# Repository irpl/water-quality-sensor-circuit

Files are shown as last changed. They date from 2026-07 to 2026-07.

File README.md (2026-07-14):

# Water Quality Sensor Interface Board — Circuit

Design files for a board that reads a water quality sensor and uploads its readings over the cellular network. Designed in **Eagle 7.6**, laid out April 2018.

The sensor speaks **RS-232**, which a microcontroller cannot read directly. An **Arduino Nano** sits behind a **MAX233** transceiver that converts the sensor's incoming RS-232 signals down to TTL serial the Nano can read. The Nano then pushes the data to a remote server over cellular using a **SIM800** module with an ordinary SIM and data plan.

It is essentially a protocol-and-transport bridge: a legacy serial instrument on one end, a cellular uplink on the other, and level translation in between.

**Server:** [watermon](https://github.com/irpl/watermon) — the listener this board uploads to.

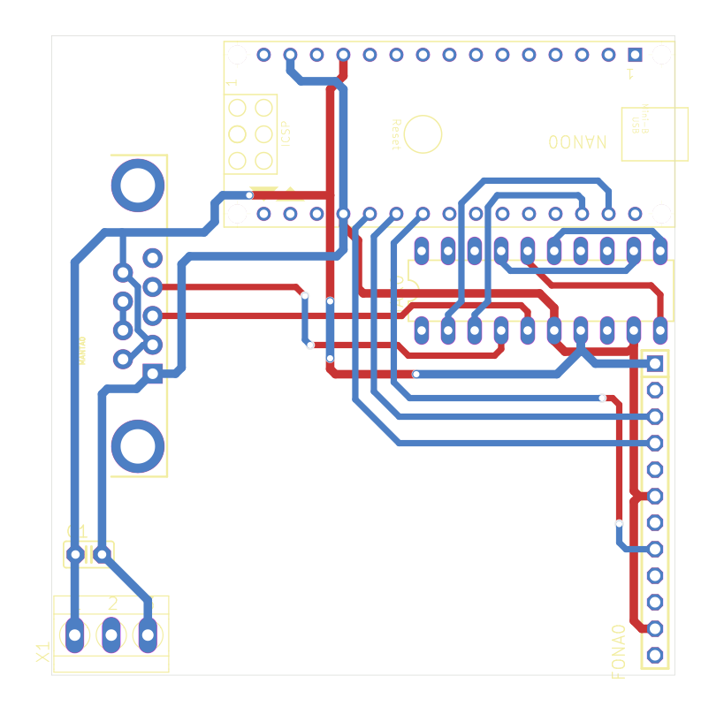
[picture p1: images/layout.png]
Copper layout


*Two-layer copper layout — red is the top layer, blue the bottom.*

## Design files

[`eagle/`](eagle/) contains the Eagle schematic (`.sch`) and board (`.brd`).

## Design notes

- **MAX233** rather than the more common MAX232: it integrates the charge-pump capacitors, so the level shifter needs no external capacitors — fewer parts to place, fewer things to fail in the field.
- **DB9 connector** on the board edge, so the sensor plugs straight in with a standard serial cable.
- Footprints for the **Arduino Nano** and the Adafruit **SIM800** cellular module, plus a 2×3 ICSP header.
- Screw terminal for field power.

The Eagle files carry no component values (only the terminal block is valued), so no BOM can be generated from them directly.

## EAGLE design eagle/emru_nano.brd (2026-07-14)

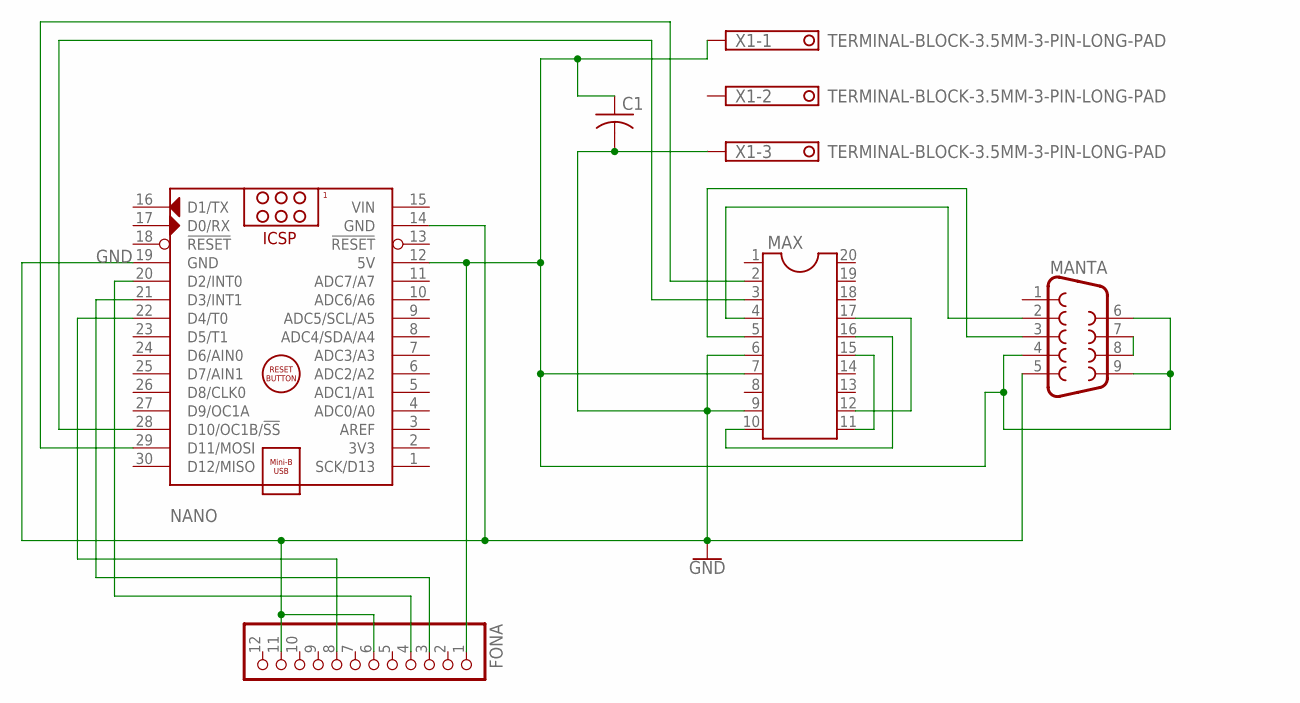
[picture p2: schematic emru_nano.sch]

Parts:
C1: C-US025-025X050; C025-025X050
FONA: PINHD-1X12; 1X12
MANTA: DB9MALE; DB9_MALE
MAX: DIL20
NANO: ARDUINO_NANO
X1: TERMINAL-BLOCK-3.5MM-3-PIN-LONG-PAD; TERMINAL-BLOCK-3-PIN-3.5MM-LONG-PAD

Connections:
GND: C1.2, FONA.6, FONA.11, MANTA.5, MAX.6, MAX.9, NANO.14 (GND), NANO.19 (GND), X1.3
unnamed: MANTA.7, MANTA.8
unnamed: FONA.4, NANO.20 (D2/INT0)
unnamed: C1.1, FONA.1, MANTA.4, MANTA.6, MANTA.9, MAX.7, NANO.12 (5V), X1.1
unnamed: MAX.10, MAX.16
unnamed: MAX.11, MAX.15
unnamed: MAX.12, MAX.17
unnamed: MANTA.2, MAX.4
unnamed: MANTA.3, MAX.5
unnamed: MAX.2, NANO.29 (D11/MOSI)
unnamed: MAX.3, NANO.28 (D10/OC1B/!SS)
unnamed: FONA.3, NANO.21 (D3/INT1)
unnamed: FONA.8, NANO.22 (D4/T0)
VIN: NANO.15 (VIN)

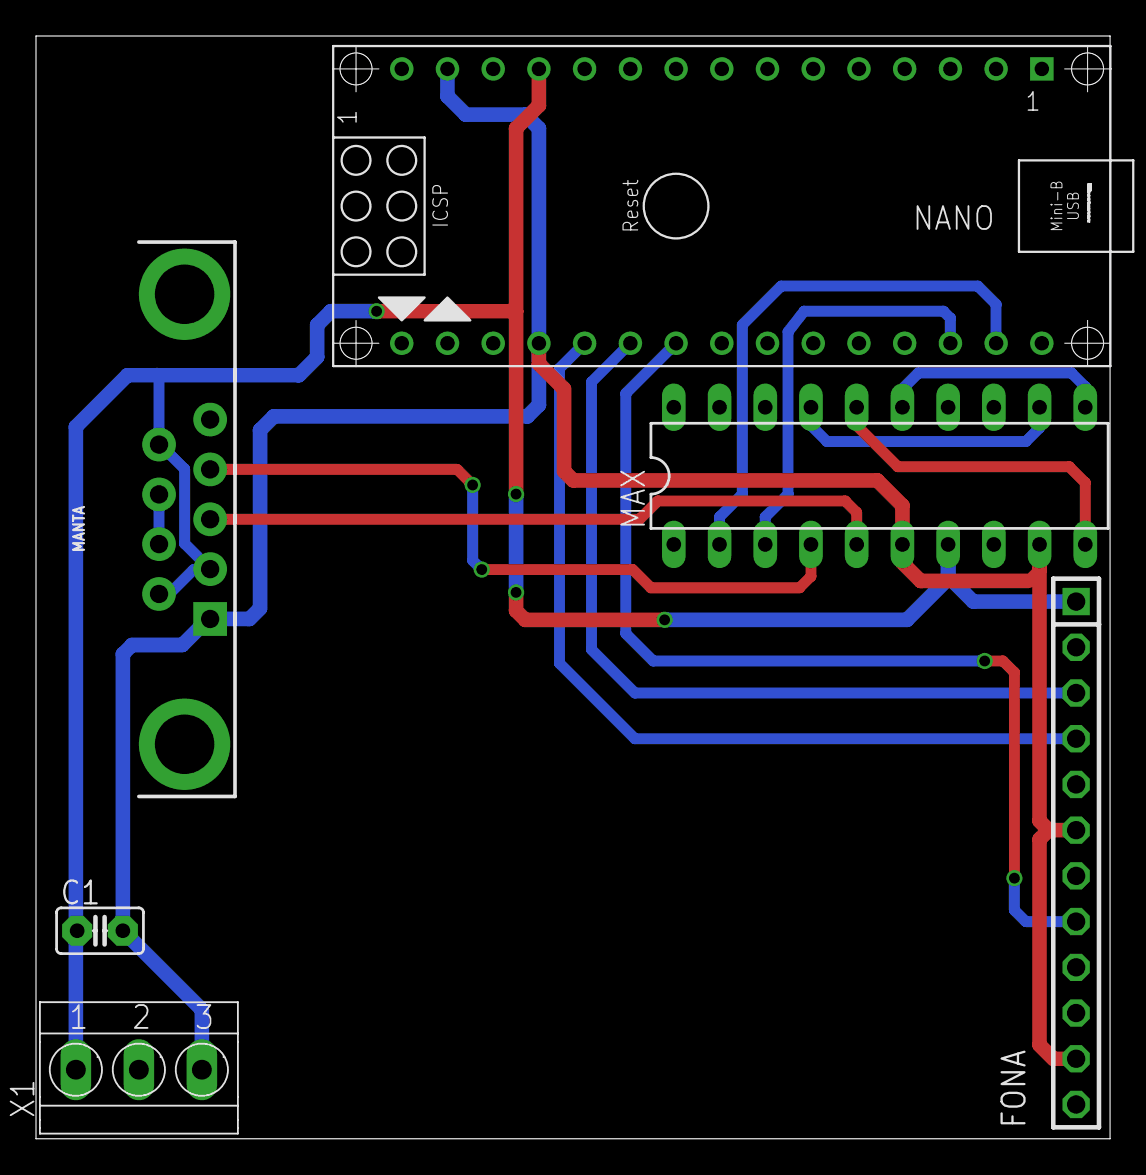
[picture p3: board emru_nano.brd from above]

Board: 2 copper layers, 59.7 x 61.3 mm, 6 parts (0 on the bottom side), 13 nets.

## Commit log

2026-07-14 Add water quality sensor interface board Eagle design files
    [emru_nano.brd, emru_nano.sch]
2026-07-14 Correct design notes: MAX233 is soldered, not socketed; no reset button

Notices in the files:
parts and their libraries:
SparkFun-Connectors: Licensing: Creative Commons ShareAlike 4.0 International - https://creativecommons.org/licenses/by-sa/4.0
